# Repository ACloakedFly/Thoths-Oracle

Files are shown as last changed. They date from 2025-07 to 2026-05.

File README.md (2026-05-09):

# Thoth's Oracle
## Table of Contents:
- [Features](#Features)
- [Make your own](#Make-your-own)
- [How it works](#How-it-works)
  - [Hardware](#Hardware)
  - [Software](#Software)
  - [Firmware](#Firmware)
- [Configuration](#Configuration)
- [FAQ](#FAQ)
- [Installation](#Installation)
  - [Windows](#Windows)
    - [Launch on startup](#Windows-launch-on-startup)
  - [Linux](#Linux-Tested-on-Ubuntu)
    - [Example](#Example)
    - [GNOME Specific](#GNOME-Specific)
    - [Linux launch on startup](#Linux-launch-on-startup)
    - [Phone Connection](#Phone-connection-to-linux)
- [License](#License)

### USB operated media display/controller for Windows, Linux(, MacOS WIP).

USB music display helps you keep track of what you are listening to without taking up precious screen space. Thoth's Oracle provides a one stop shop for checking on the current media information and basic controls such as skipping tracks, playing and pausing and adjusting the volume.



# Features:

- Software agnostic companion app listens to operating system rather than a specific program like Spotify app or Firefox
  - If OS is aware of media, companion app will be as well
- 320x480 IPS display for maximum readability
- Display the available metadata of current media
  - Thumbnail
  - Title
  - Album
  - Artist
  - Duration and current position
- Basic media control
  - Play/pause
  - Skip track
  - Previous track
  - Mute/unmute
  - Volume control
- Tiltable screen
- Brightness control
- Lightweight companion app (peak RAM usage <80MB, avg <50MB)
- Wallpaper mode to cycle through local images in Wallpaper folder
- Standard components allowing for custom configuration and ease of assembly
  - Hotswappable MX style or Kailh Choc low-profile style switches
  - 6mm rotary potentiometer and encoder
  - 3D printed shell
  - One screw size
  - Small PCB with mostly THT components. Only the hotswap sockets are SMD (hand solderable)

# Make your own!

Everything you need to make your own should be in BOM-and-Assembly. Let me know if anything can be improved.

# How it works:

## Hardware:

- An ESP32-S3 zero controls all of the device inputs and displays information on screen
- ESP32 communicates with PC over USB C OTG connection

## Software:

- The software is written in C# for the Windows App.
- Companion app catches changes to focused media broadcast from the operating system.
- On media change, Thoth requests metadata, packages it, then waits for signal from the Oracle that it is ready to receive the data.
- Metadata is packaged as follows with header tag denoting type, size, etc.:
  - System information containing date and time
  - Media duration and position
  - Media text: title, album, artist
  - Thumbnail
- All text is converted to UTF-8.
- Once ready signal is received, Thoth sends a package over serial port, waits for ready signal, then proceeds to next package.
- When input commands are received, Thoth requests the OS completes the action.

## Firmware:

- The firmware is written in C.
- All serial communications are handled by Core 1. Core 0 handles all display features running LVGL.
- Thoth's Oracle emits ready signal periodically while idling, and emits control commands as soon as they are inputted by the user.
- When data is received, the header tag is analyzed to know which buffer it should be put in.
- If there is an error with the header tag, all subsequent data is dumped, and firmware waits for a pause in data transmission before resetting header information and buffers, and returning to idle state.
- If no errors are detected, data is placed directly into the correct buffer for further analysis in the case of text data, or displayed immediately for images (rolling effect as image loads).
- Media text starts as one big array of characters, and is split into the three fields using escape characters inserted by companion app.
- The font used is DejaVu-Sans in 16 point, with as much of the character set as is hopefully reasonable to ensure maximum language compatibility, without containing the entire set.
- Once the expected number of bytes is received based on the header tag, the header is reset, Oracle emits a ready signal, then enters idle state.
- If firmware times out before receiving expected data, header tag is reset and device enters idle state.

# Configuration:

 The following can be configured from companion app or config file
- Which program to listen to
- Port the device is connected to
- Sensitivity of volume knob
- Which output device to control (default, speakers, headphones, etc.)
- Wallpaper mode

# FAQ:

Someone ask me something, please.

# Installation:

### Windows:

Companion app is provided as portable application that doesn't need installation. Just download and extract the software file for your system wherever you want and run it!

#### Windows launch on startup:
- Right click on .exe and select 'Create shortcut'
- Copy the shortcut to %APPDATA%\Microsoft\Windows\Start Menu\Programs\Startup

### Linux (Tested on Ubuntu):

- Extract folder to desired location.
- Edit .desktop file to match new location if you want app to appear in Apps list.
- Validate and install
```
desktop-file-validate thoths_oracle.desktop
desktop-file-install thoths_oracle.desktop
```
- Check which port Oracle is connected to. It should show up as USB ACM device.
- Verify the device's group permissions are rw and note the group.
- Verify you are part of the group.
- Reboot
#### Example:

```
$ sudo dmesg | grep tty
[    0.139832] printk: legacy console [tty0] enabled
[    6.652489] cdc_acm 1-5.2.2:1.0: ttyACM0: USB ACM device
$ sudo chmod g+rw /dev/ttyACM0
$ ls -ld /dev/ttyACM0
crw-rw---- 1 root dialout 166, 0 Dec  2 18:21 /dev/ttyACM0
$ sudo usermod -a -G dialout dominique
$ sudo reboot
```
#### GNOME Specific:
GNOME may need an extension such as [AppIndicator and KStatusNotifierItem Support](https://extensions.gnome.org/extension/615/appindicator-support/) to display the menu along the top panel. Otherwise, the program will run normally but all settings will have to be changed through the configuration file.

#### Linux launch on startup:
Using Startup Applications Preferences:
-  Add a new entry named Thoths Oracle.
-  If you have installed the .desktop file, set the command to gtk-launch thoths_oracle.desktop
-  Otherwise, change the command to the location you extracted Thoth's Oracle in.
    - eg. /home/dominique/Documents/Programs/Thoths_Oracle_linux/Thoths_Oracle
- Add a comment if desired and save.

#### Phone connection to Linux:
To use audio from phone with all the same features, install [GSConnect](https://github.com/GSConnect/gnome-shell-extension-gsconnect/wiki) for GNOME, or [KDE Connect](https://kdeconnect.kde.org/) for KDE Plasma and follow the instructions to set it up.  
Add kdeconnect or gsconnect to config.yaml in MonitoredProgram section.  
Next, connect phone (source) to Linux (sink) through bluetooth for audio.  
Done!  

# License:

Thoth's Oracle is licensed under GPL-3.0

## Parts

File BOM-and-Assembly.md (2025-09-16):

# BOM

## Hardware
| Qty | Item | Notes |
| ---- | -- | ---|
| 7 or 9 | M3x20 SHCS | [Example](https://www.aliexpress.com/item/32810872544.html?spm=a2g0o.order_list.order_list_main.31.5b9d1802S5DEg1) |
| 2 | M3x16 SHCS | (optional) shorter screws can be used for the thumbscrews. |
| 9 | M3x4x5 (Screw, height, outer diameter) brass heatset inserts | [Example](https://www.aliexpress.com/item/1005003582355741.html?spm=a2g0o.order_list.order_list_main.63.5b9d1802S5DEg1) |
| 2 | 6mm shaft guitar knobs | 18mm outer diameter works well. Knobs are 38mm apart, so anything larger might get tight. [Example](https://www.aliexpress.com/item/1005003800832352.html) |
| 3 | Keycaps for the switches | [Example](https://www.aliexpress.com/item/1005002976015114.html) |

## Electronics
| Qty | Item | Product Number | Notes |
| --- | -- | -- | --- |
| 1 | PCB |  | Can be purchased from PCBWay or JLCPCB or similar using the Thoths_Oracle_PCB_xxx.rar file in the latest release | 
| 1 | 3.5" 320x480 SPI display | [MSP3525](https://www.lcdwiki.com/3.5inch_IPS_SPI_Module_ST7796) | ST7796U will work, ILI9488 should work but has not been tested. [link](https://www.aliexpress.com/item/1005005878590372.html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) to the IPS display I use. |
| 1 | ESP32-S3 zero | [ESP32-S3-Zero](https://www.waveshare.com/wiki/ESP32-S3-Zero) | As long as it has the ESP32-FH4R2 chip it will work. Presoldered headers are nice |
| 3 | Mechanical keyboard switches |  | Standard MX pinout or Kailh Choc V2 will work. [MX](https://www.cherry.de/en-gb/product/mx2a-red), [Choc V2](https://www.kailh.net/products/kailh-choc-v2-low-profile-switch-set)|
| 3-6 | Matching hotswap sockets | [PG1511](http://www.kailh.com/en/Products/Ks/HPC/), [PG1350](https://cdn.shopify.com/s/files/1/0588/1108/9090/files/5118-Choc-Socket.pdf?v=1686715063) | PG1511 for standard, or PG1350 for Choc V2. Both types can be installed on the same switch location if you want to experiment. |
| 1 | EC11 rotary encoder | [EC11E15244G1](https://tech.alpsalpine.com/e/products/detail/EC11E15244G1/) | A 12.5mm long shaft will work. Longer would be better. |
| 1 | RV09 rotary potentiometer | [RV09BCF-40](https://www.taiwanalpha.com/downloads?target=products&id=72) | A 12.5mm long shaft will work. Longer would be better. |
| 2 | female header sockets 1x9 pins | [66951-009LF](https://www.digikey.com/en/products/detail/amphenol-cs-fci/66951-009LF/1002554) | Ideally 8.4mm insulation height. Longer header sockets can be cut shorter (eg. 1x20 cut to two 1x9s) |
| 1 | XH 2.5mm horizontal male header 1x8 pins | [S8B-XH-A-1](https://www.digikey.com/en/products/detail/jst-sales-america-inc/S8B-XH-A-1/9961927) |
| 1 | JST 2.5mm connector cable 1x8 pins | [XHP-8](https://www.digikey.com/en/resources/datasheets/jst/xh-connector) | These can be found as [preassembled cables](https://www.aliexpress.com/item/4000698884218.html?spm=a2g0o.order_list.order_list_main.5.5e661802USnLWp). At least 5cm is needed but it might be hard to route. 10cm works fine. |
| 1 | USB-C data cable | | C to C or C to A depending on your preference |

## 3D Prints
| Qty | Item |
| --- | -- |
| 1 | Oracle_inputs_plate.stl |
| 1 | Oracle_inputs.stl |
| 1 | Oracle_screen_plate.stl |
| 1 | Oracle_screen.stl |
| 2 | Oracle_thumbscrew.stl |
| 2 | Oracle_thumbscrew_cap.stl |

# Shell Instructions

## 3D Printing

All STLs are in the correct orientation for printing. The Oracle_inputs STL is the only one that needs supports. Any stiff material should work fine (I used PLA).
Here are the support settings I have found to work well
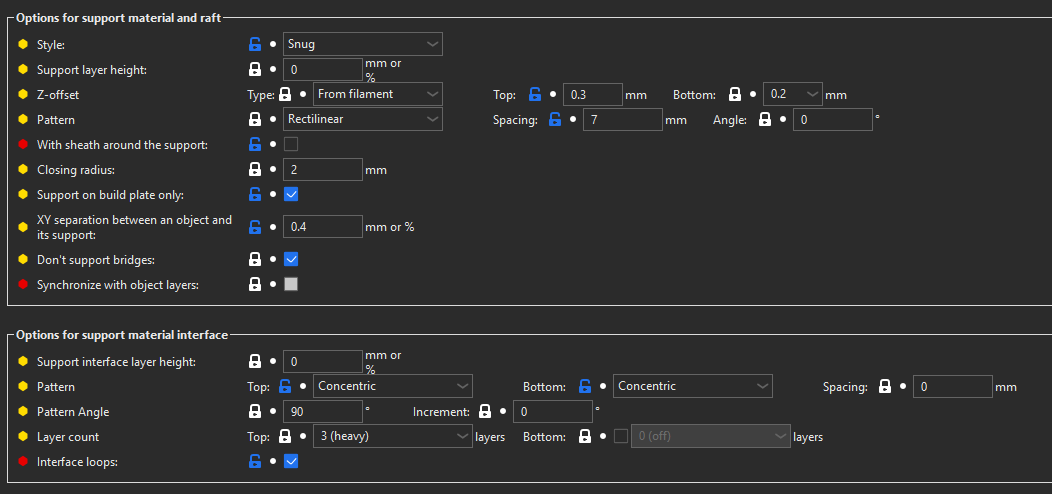
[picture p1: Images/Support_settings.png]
Support_settings


# PCB Assembly and Heat Sets Instructions

**Disclaimer:** I am not the best solderer. This is more for where everything goes, and an order that works. You do not need to be a highly skilled solderer to do this. 
If you are new at this, I recommend watching tutorials and safely practicing a bit. 

**Required Tools and Materials**
- Solder
- Soldering iron
- Ventilation fan
- Safety glasses
- M2.5 hex bit
- M2.0 hex bit
- Flush cutters
- Pliers

Collect the components. Only one set of hot swap sockets is required, both can be used.

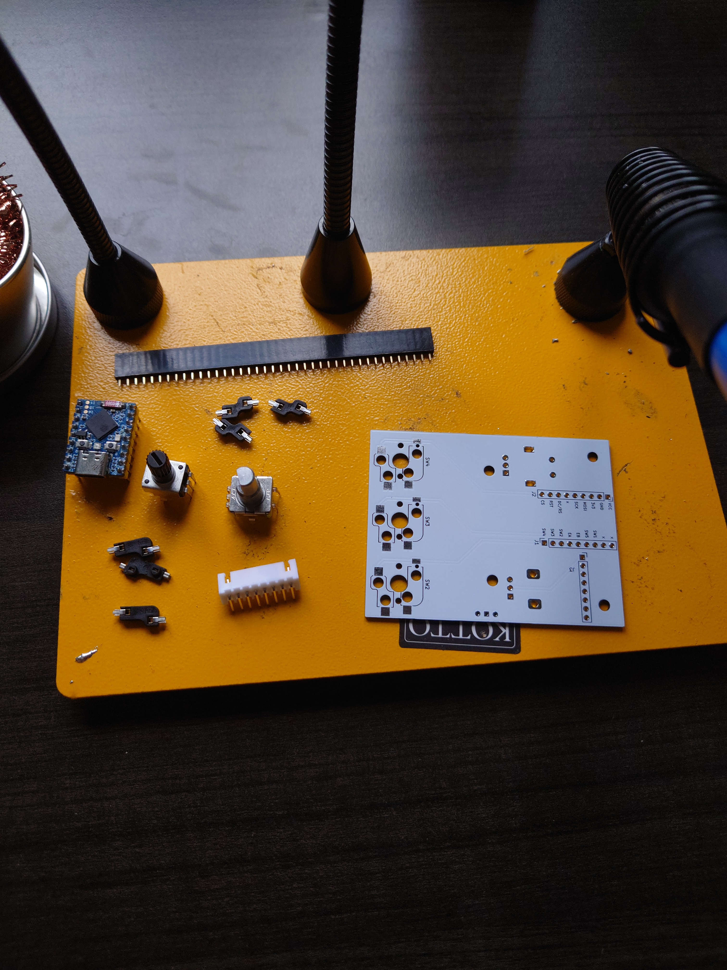
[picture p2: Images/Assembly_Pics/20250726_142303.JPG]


If you are using header sockets longer than 9 pins, snip across the 10th.

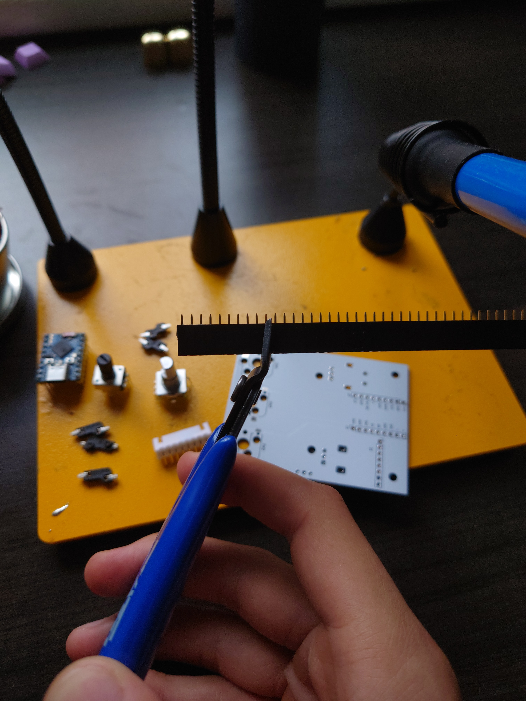
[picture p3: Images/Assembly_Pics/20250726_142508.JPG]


The cut end will need to be cleaned up. This can be done with the snips.

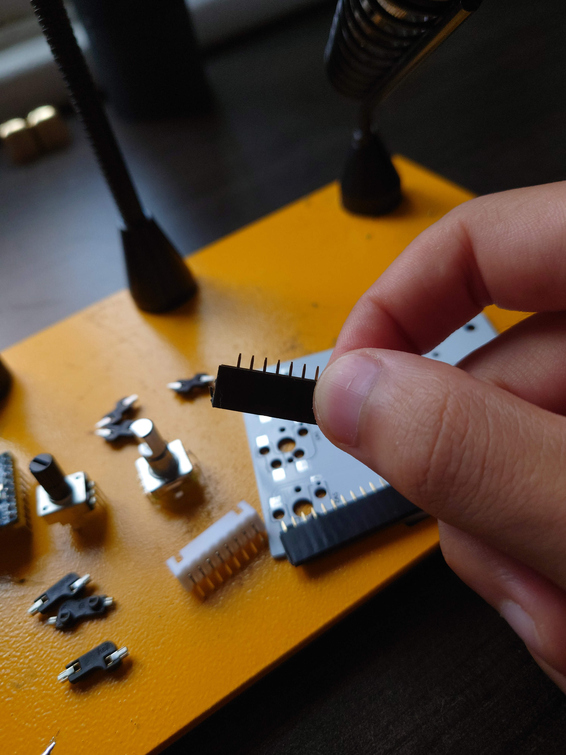
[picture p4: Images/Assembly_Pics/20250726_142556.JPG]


Try not to cut too far into the next socket. Repeat for the second row.

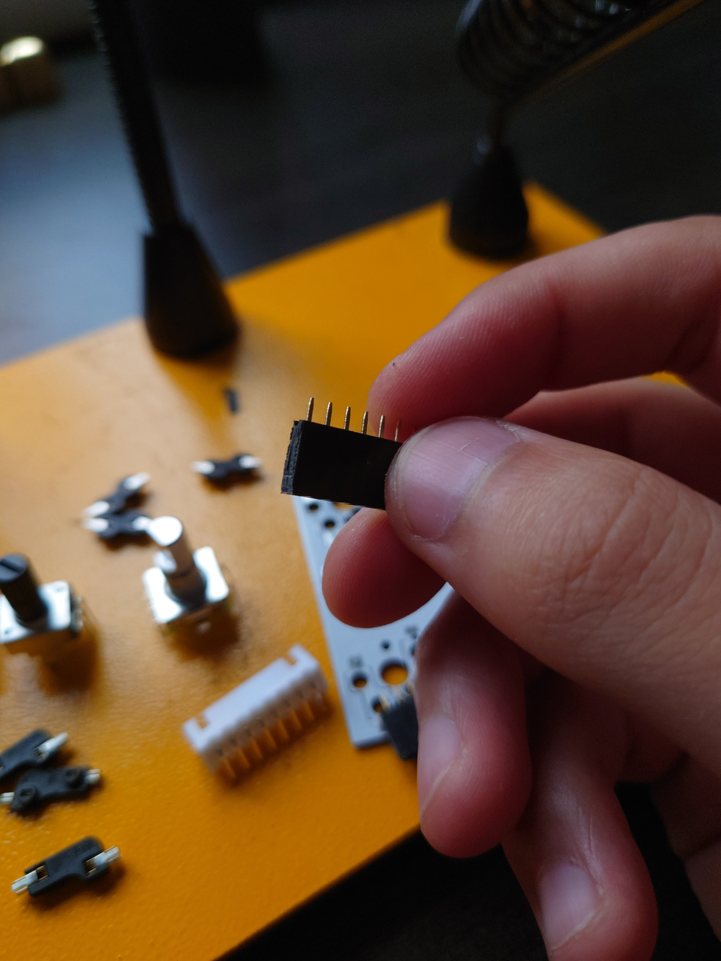
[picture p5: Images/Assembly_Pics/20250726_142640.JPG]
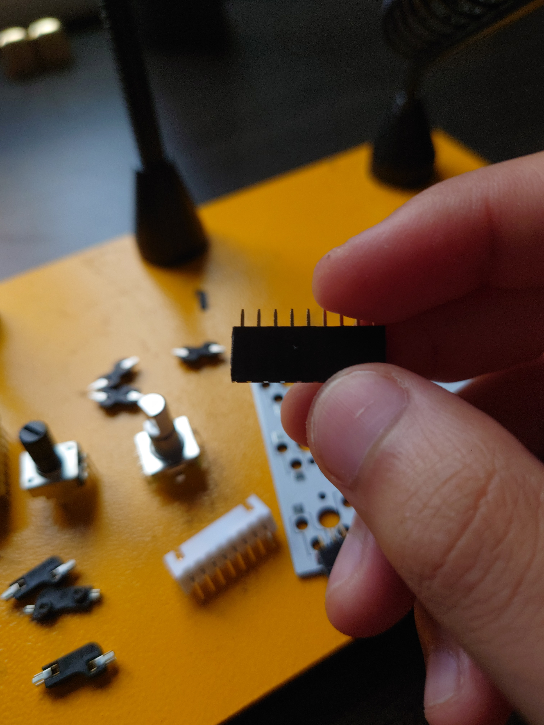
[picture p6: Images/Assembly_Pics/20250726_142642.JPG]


Depending on which hot swap sockets you are using, place them in the corresponding holes and solder them onto the pads.

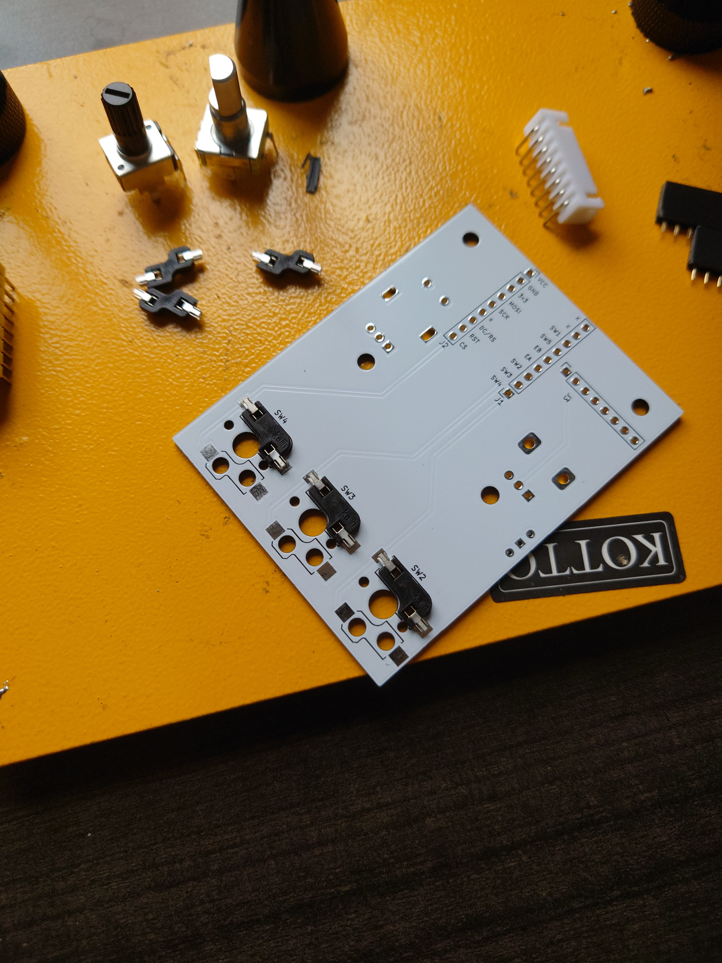
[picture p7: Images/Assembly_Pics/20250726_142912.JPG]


Yikes! But it will do. These are only switches, so precision is not required.

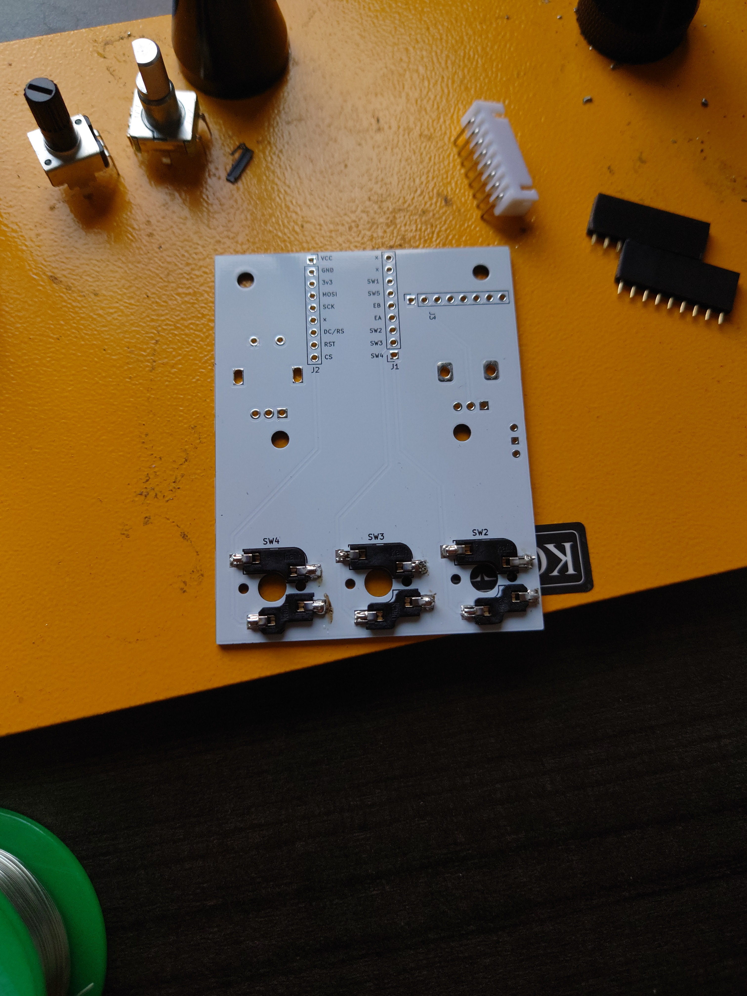
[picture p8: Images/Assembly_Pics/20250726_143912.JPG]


The pins for the screen go on the same side as the hotswap sockets. So solder them from the top of the board.



For the ESP32, placing the sockets on its header pins keeps them straight.



They also go on the bottom of the board, same as the screen pins. If you are worried about overheating the ESP32, solder a couple pins on each row to keep them steady, then remove the ESP32.



The rotary encoder and potentiometer go on the top of the board.



Hopefully your board looks better than mine!



Soldering is complete!
The iron will still be needed for the heat set inserts.

All the heat set inserts should be pressed flush with their top surfaces. A few of them are fairly close to tall walls, so I found it easier to press them in with the side of the soldering tip once they were hot enough to go in with not much force.





That's the end of the soldering iron.

# Final Assembly Instructions

The PCB goes into the shell with the ESP facing outwards.



As you slide the PCB into the shell, pull the wall with USB hole away from the ESP32 slightly to clear the USB port. The port should fit snuggly into the hole afterwards.



Screw the inputs plate onto the shell



Line up the screen with the heat sets and connect the ribbon cable. Make sure GND through LED are the ones connected.



Screw the screen plate on.



Line up the plug with the hole in the inputs shell, then push it in until it is fully seated.



The two halves can now be put together. It will be a tight fit.



Place the screw as far into the thumbscrew without pushing the head into it. The cap needs to be aligned with the screw first.



Push the cap into the head and line the tabs up with the hole.



Flip the whole thing over and push the thumbscrew down until everything is pressed into place. Repeat these steps for the second thumbscrew.



Screw each thumbscrew into the screen.



Depending on the length of your potentiometer and encoder shafts, the knobs might drag along the shell. So lift them up a little before securing them with the grub screw. This is especially important for the encoder to keep the switch functioning.



Try to make sure the pins on your switches are fairly straight. The pin on the left might be too crooked to fit nicely. 



Line up the pins and push the switches into place. The keycaps go on next.



Your build is complete!



# Firmware Flashing Instructions

- Connect your ESP32 to your computer with a USB cable, then find out which port it is connected to either using Thoth's Oracle Software or through your OS.
- Download the ESP flashing tool from [here](https://docs.espressif.com/projects/esp-test-tools/en/latest/esp32s3/production_stage/tools/flash_download_tool.html), then extract the folder.
- Download and extract the latest release of Thoths_Oracle_Firmware. Place all three files into the bin folder of the flashing tool.
- Run the flashing tool exe.
- Set the chip type to ESP32-S3, Workflow to Develop, and Load mode to UART, then click OK.
- Set up the next screen according to the screenshot below, ensuring the COM matches the port your ESP32 is connected to.
- Press start and let the tool finish.
- The tool does not restart the ESP32, so if you are doing this when the Oracle is assembled, disconnect and reconnect the USB cable and it should start displaying. 
  
flashing_instructions

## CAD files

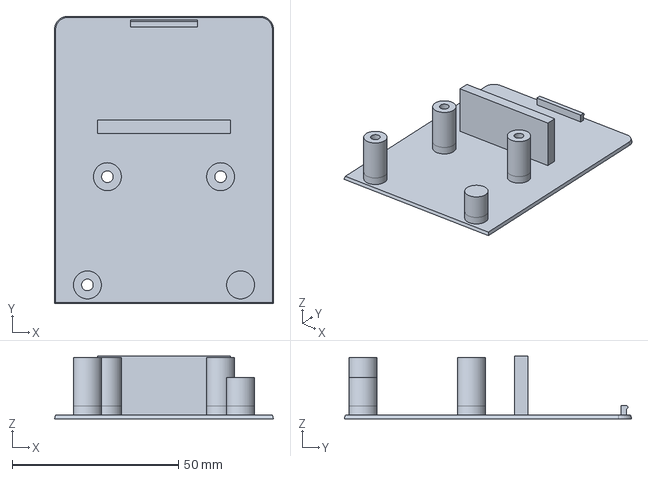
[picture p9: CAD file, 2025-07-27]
Shell/CAD/Oracle_inputs_plate.FCStd
65.8 x 86.3 x 18.8 mm

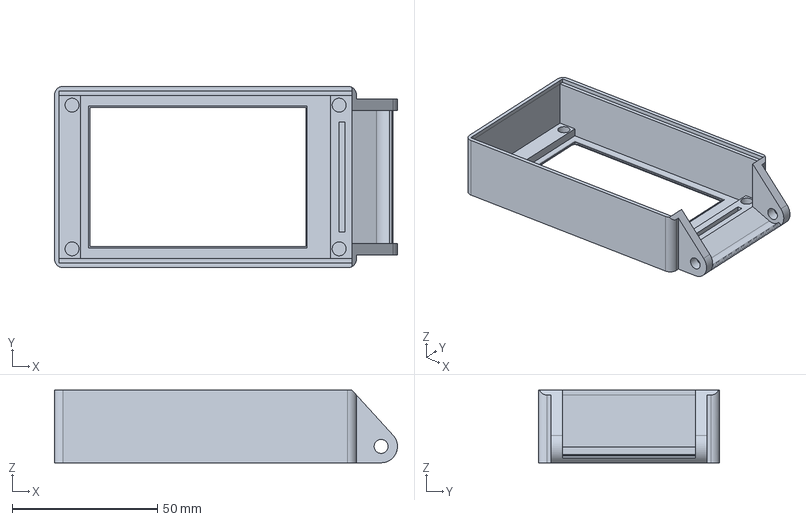
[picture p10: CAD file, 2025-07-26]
Shell/CAD/Oracle_screen.FCStd
118.1 x 62.5 x 25.0 mm

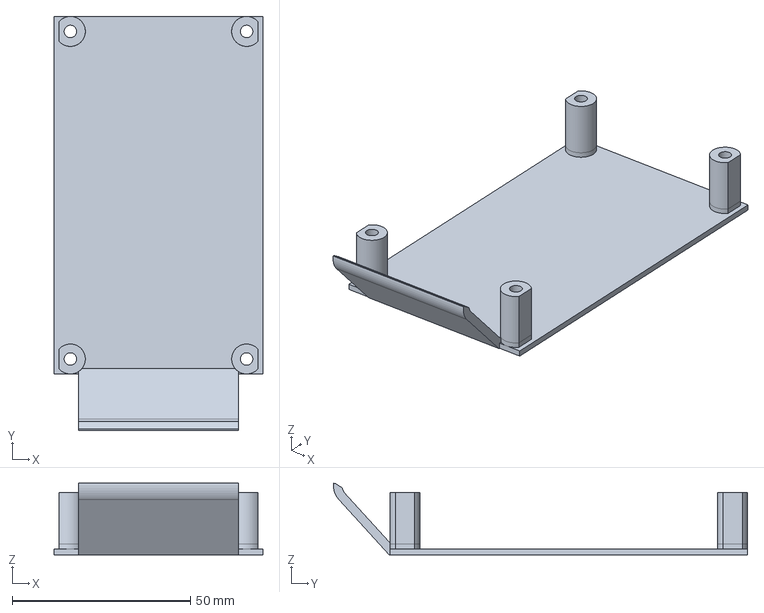
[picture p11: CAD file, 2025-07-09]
Shell/CAD/Oracle_screen_plate.FCStd
58.7 x 116.3 x 20.1 mm

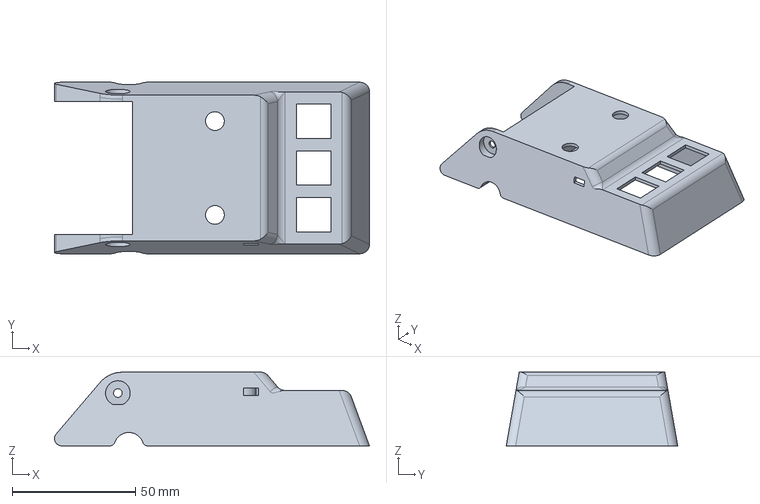
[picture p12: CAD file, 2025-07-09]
Shell/CAD/Oracle_inputs.FCStd
127.7 x 69.5 x 29.9 mm

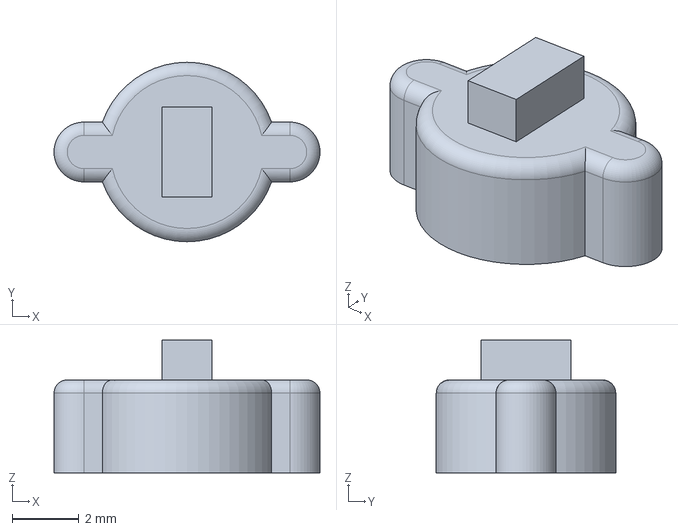
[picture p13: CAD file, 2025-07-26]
Shell/CAD/Oracle_thumbscrew_cap.FCStd
8.00 x 5.40 x 4.00 mm

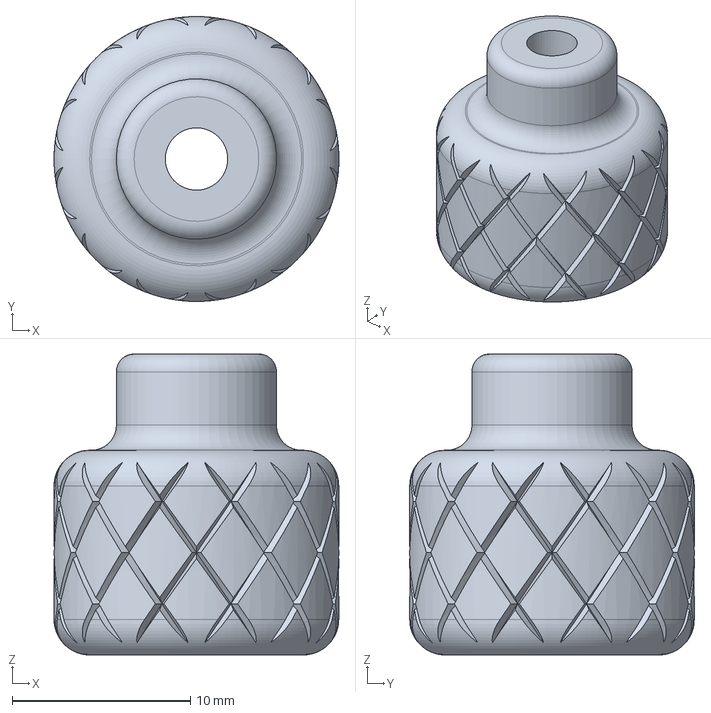
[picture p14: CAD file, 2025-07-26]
Shell/CAD/Oracle_thumbscrew.FCStd
16.0 x 16.0 x 16.9 mm

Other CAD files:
Shell/STLs/Oracle_inputs.stl
Shell/STLs/Oracle_inputs_plate.stl
Shell/STLs/Oracle_screen.stl
Shell/STLs/Oracle_screen_plate.stl
Shell/STLs/Oracle_thumbscrew.stl
Shell/STLs/Oracle_thumbscrew_cap.stl

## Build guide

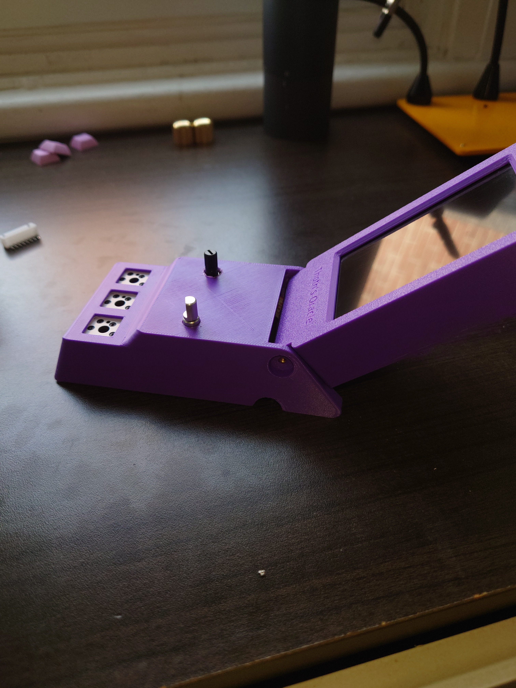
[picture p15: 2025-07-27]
Images/Assembly_Pics/20250726_150715.JPG

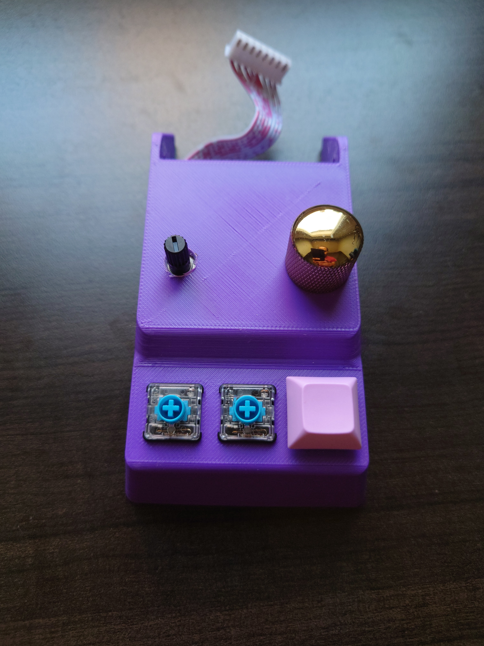
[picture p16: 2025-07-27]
Images/Assembly_Pics/20250724_144334.JPG

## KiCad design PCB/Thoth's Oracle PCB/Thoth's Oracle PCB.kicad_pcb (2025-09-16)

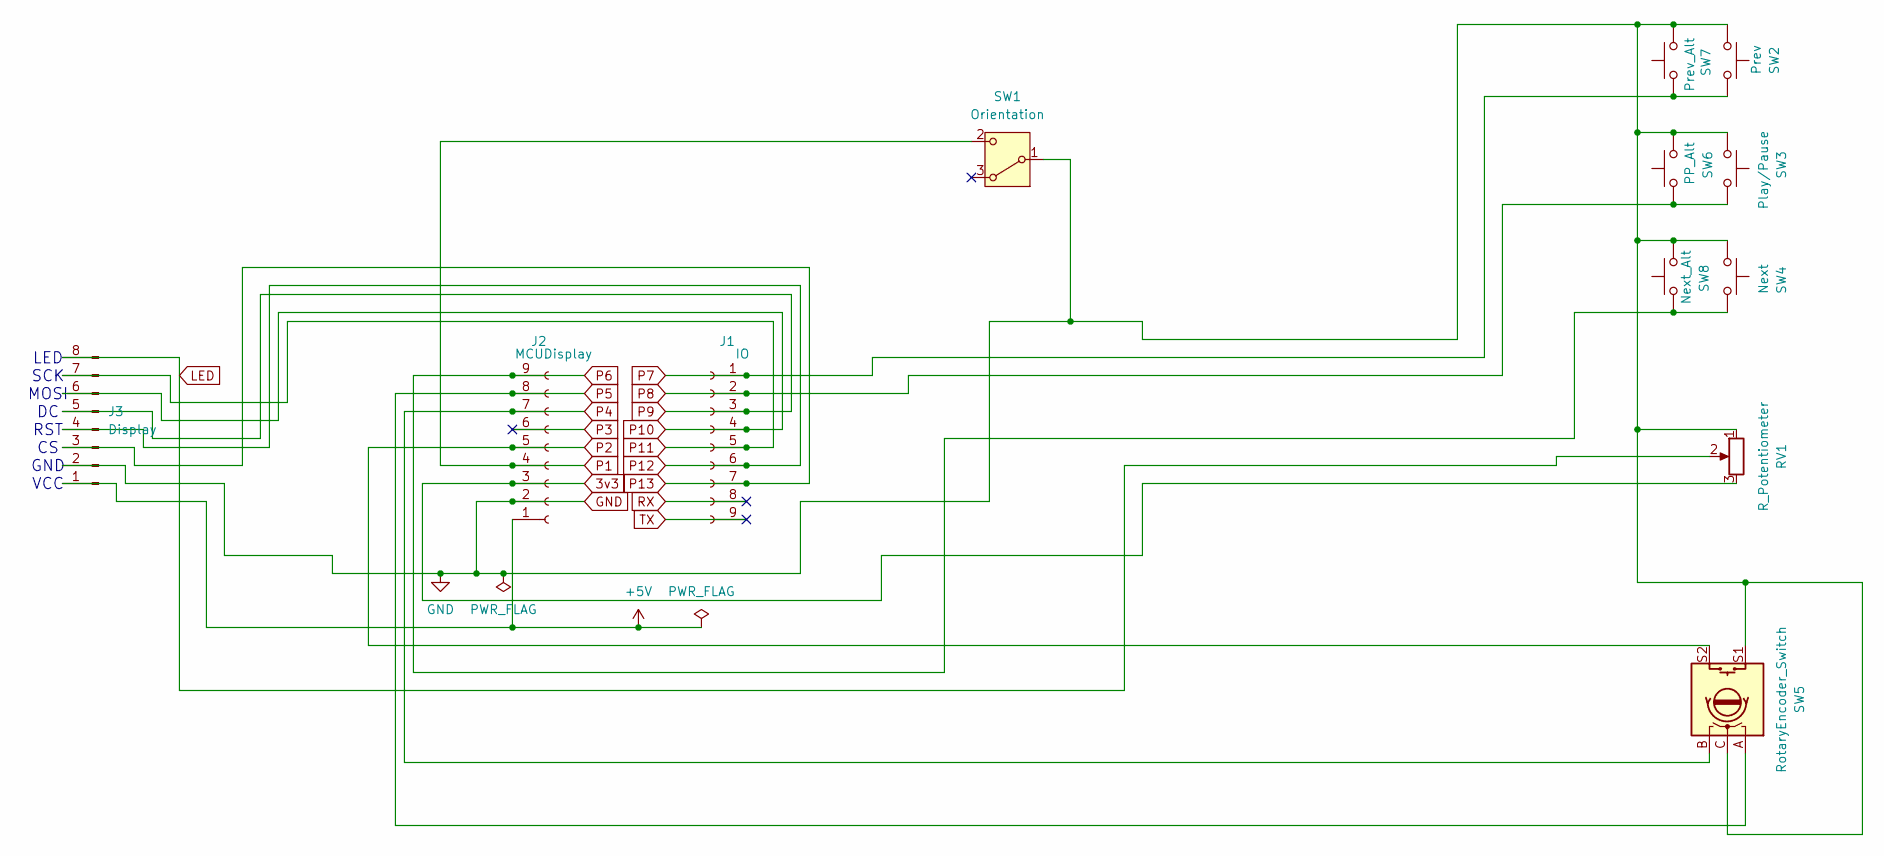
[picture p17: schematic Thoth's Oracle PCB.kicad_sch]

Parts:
J1: IO; PinSocket_1x09_P2.54mm_Vertical
J2: MCUDisplay; PinSocket_1x09_P2.54mm_Vertical
J3: Display; PinSocket_1x08_P2.54mm_Horizontal
RV1: R_Potentiometer; Potentiometer_Alps_RK09K_Single_Vertical
SW1: Orientation; SW_Slide-03_Wuerth-WS-SLTV_10x2.5x6.4_P2.54mm
SW2: Prev; Kailh_socket_MX_modified
SW3: Play/Pause; Kailh_socket_MX_modified
SW4: Next; Kailh_socket_MX_modified
SW5: RotaryEncoder_Switch; RotaryEncoder_Alps_EC11E-Switch_Vertical_H20mm
SW6: PP_Alt; Kailh_socket_PG1350_modified
SW7: Prev_Alt; Kailh_socket_PG1350_modified
SW8: Next_Alt; Kailh_socket_PG1350_modified

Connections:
3v3: J2.3, RV1.3
+5V: J2.1, J3.1
GND: J2.2, J3.2, RV1.1, SW1.1 (B), SW2.2, SW3.2, SW4.2, SW5.C, SW5.S1, SW6.2, SW7.2, SW8.2
LED: J3.8, RV1.2
P1: J2.4, SW1.2 (C)
P2: J2.5, SW5.S2
P3: J2.6
P4: J2.7, SW5.B
P5: J2.8, SW5.A
P6: J2.9, SW4.1, SW8.1
P7: J1.1, SW2.1, SW7.1
P8: J1.2, SW3.1, SW6.1
P9: J1.3, J3.5
P10: J1.4, J3.6
P11: J1.5, J3.7
P12: J1.6, J3.4
P13: J1.7, J3.3
RX: J1.8
TX: J1.9

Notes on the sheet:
LED SCK MOSI DC RST CS GND VCC

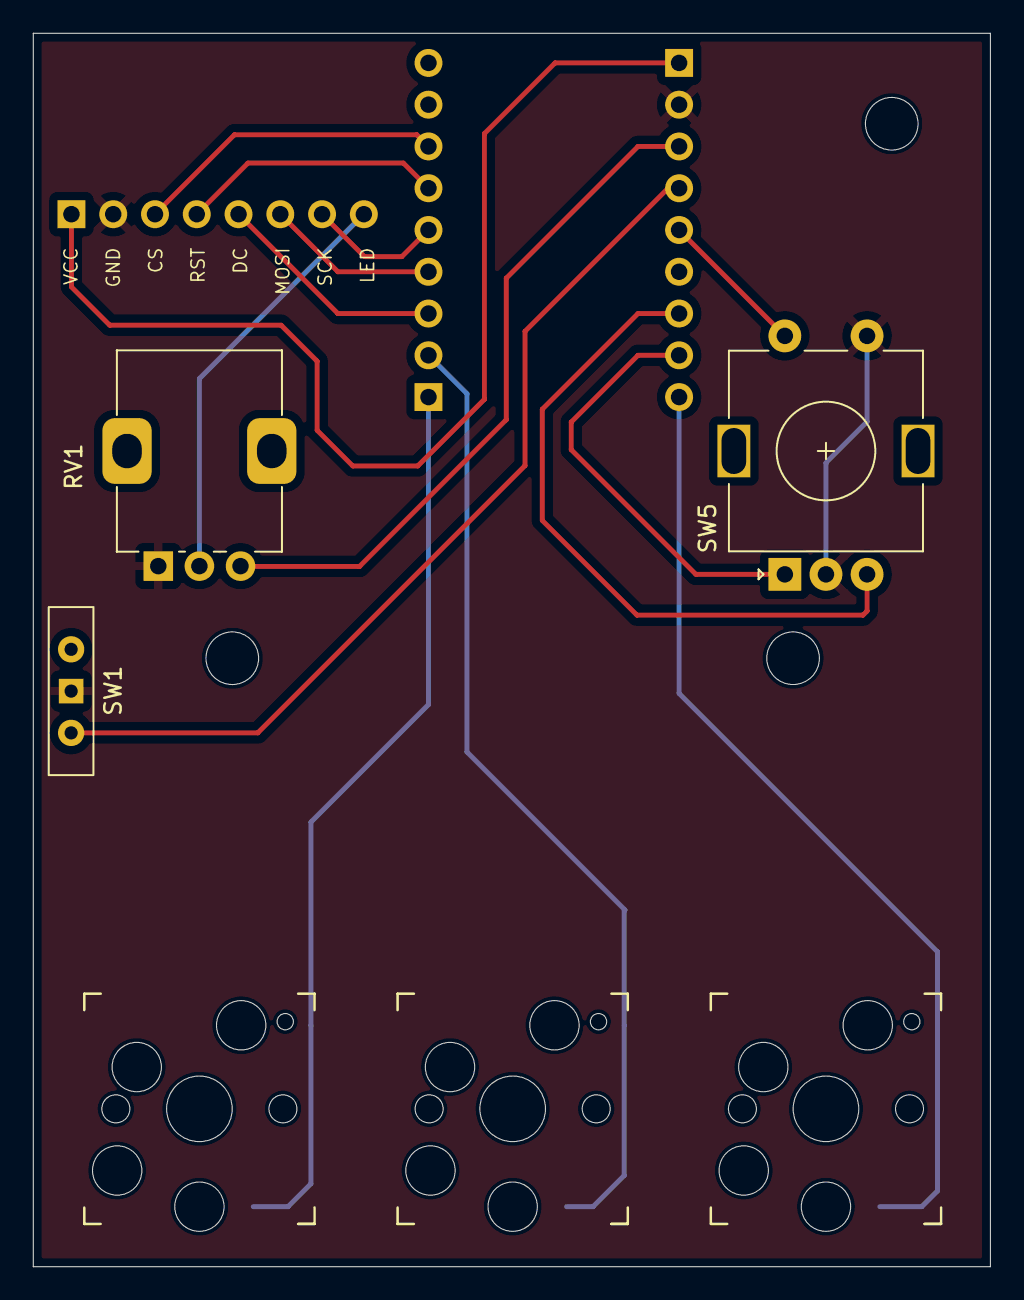
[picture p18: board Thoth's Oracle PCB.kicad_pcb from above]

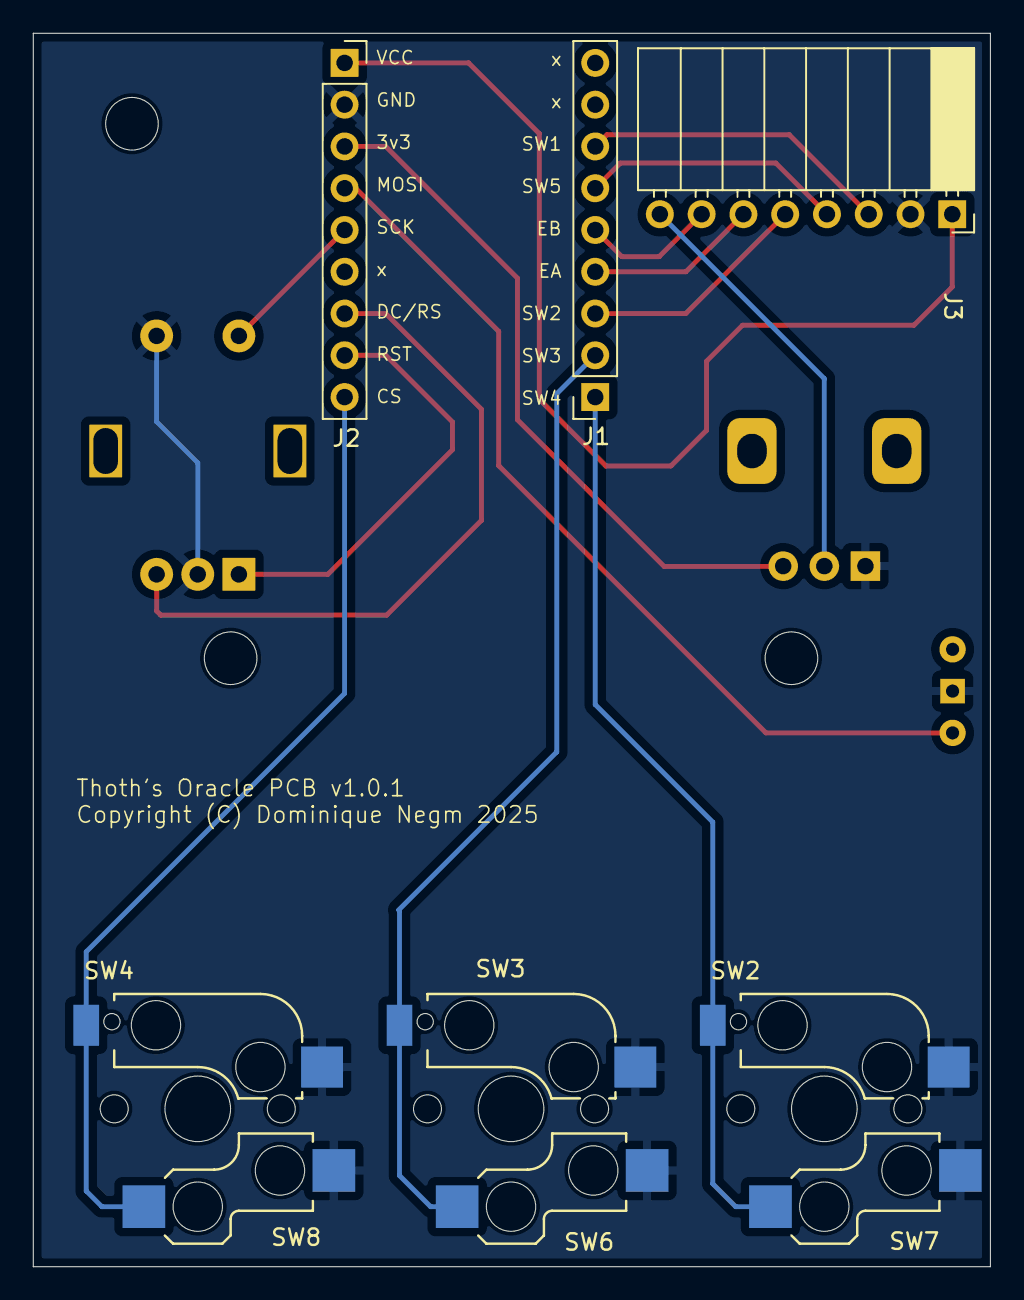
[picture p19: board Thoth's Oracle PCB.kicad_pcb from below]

Board: 2 copper layers, 58.2 x 75.0 mm, 12 parts (3 on the bottom side), 16 nets.

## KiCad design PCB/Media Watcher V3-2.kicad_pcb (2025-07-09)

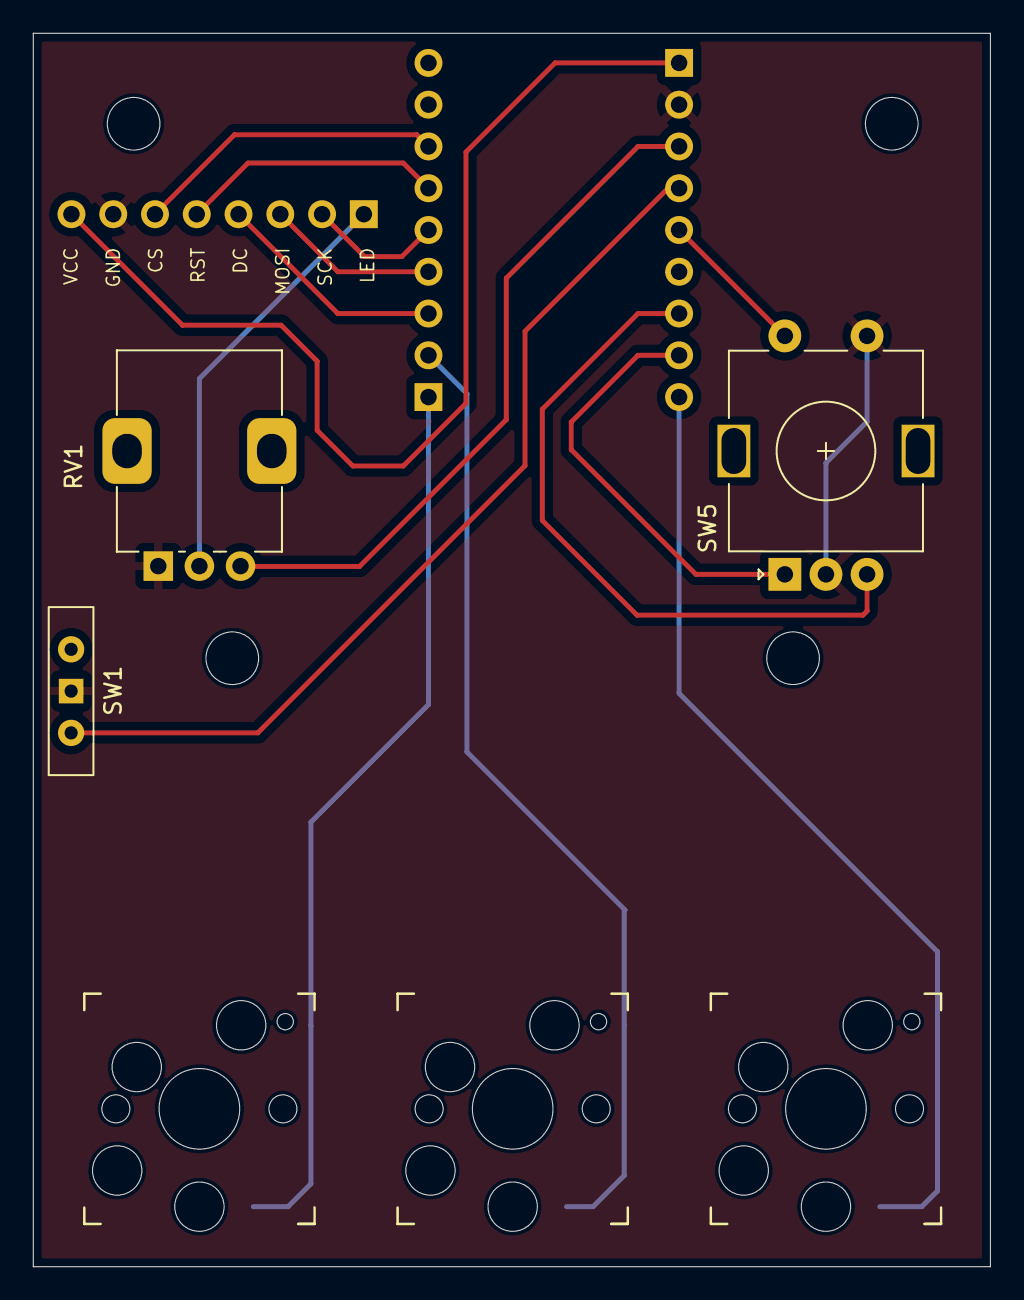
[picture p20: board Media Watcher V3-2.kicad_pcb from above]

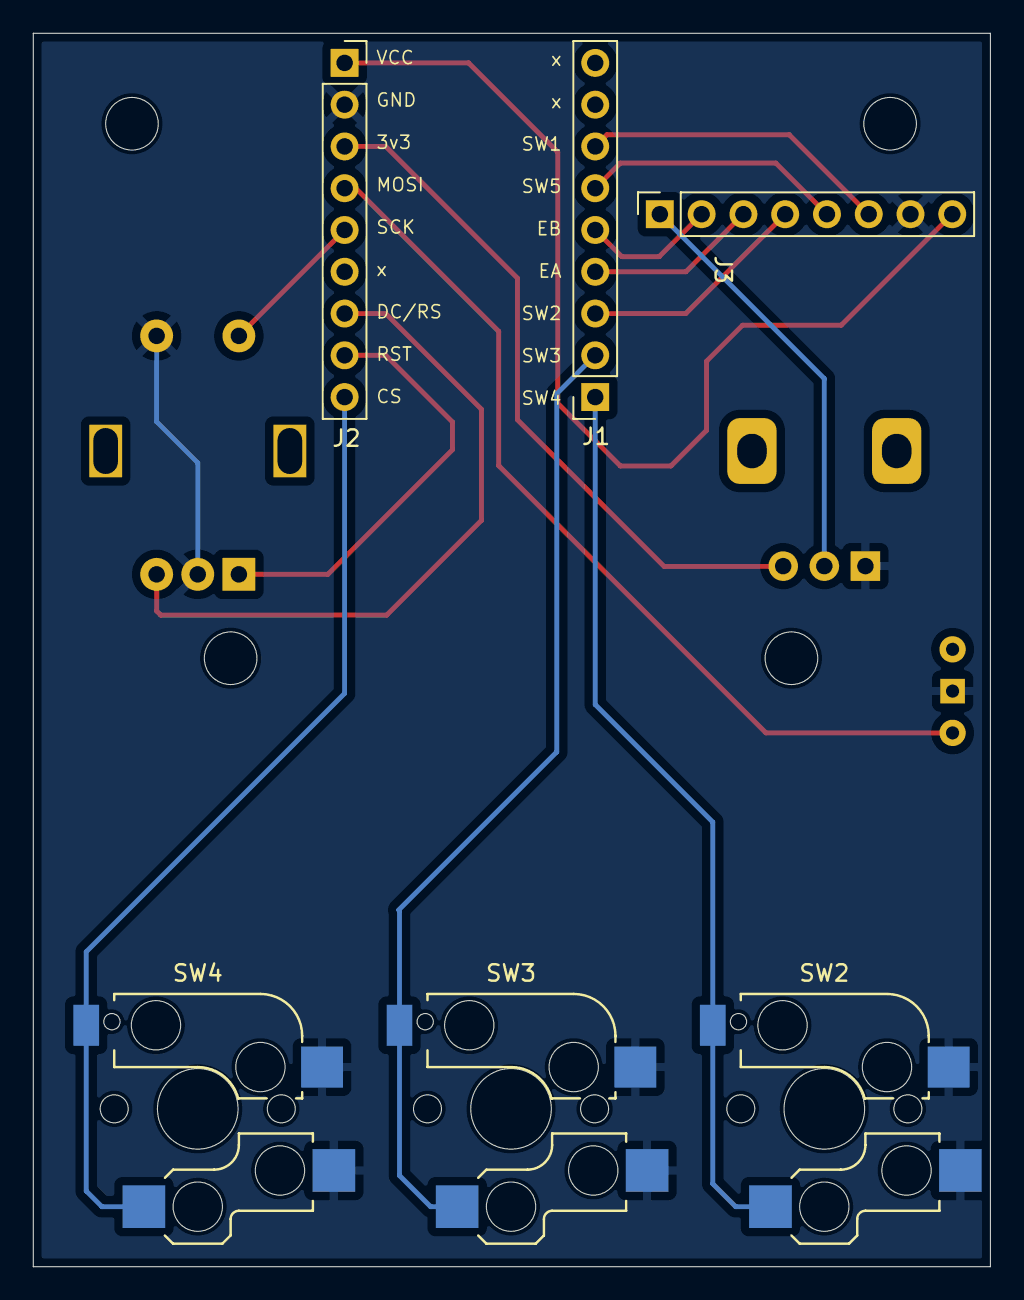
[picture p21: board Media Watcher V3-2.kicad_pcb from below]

Board: 2 copper layers, 58.2 x 75.0 mm, 9 parts (3 on the bottom side), 16 nets.

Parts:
J1: IO; PinSocket_1x09_P2.54mm_Vertical
J2: MCUDisplay; PinSocket_1x09_P2.54mm_Vertical
J3: Display; PinSocket_1x08_P2.54mm_Vertical
RV1: R_Potentiometer; Potentiometer_Alps_RK09K_Single_Vertical
SW1: Orientation; SW_Slide-03_Wuerth-WS-SLTV_10x2.5x6.4_P2.54mm
SW2: Prev; Kailh_socket_MX_PG1350
SW3: Play/Pause; Kailh_socket_MX_PG1350
SW4: Next; Kailh_socket_MX_PG1350
SW5: RotaryEncoder_Switch; RotaryEncoder_Alps_EC11E-Switch_Vertical_H20mm

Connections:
3v3: J2.3, RV1.3
+5V: J2.1, J3.8
GND: J2.2, J3.7, RV1.1, SW1.1 (B), SW2.2, SW3.2, SW4.2, SW5.C, SW5.S1
LED: J3.1, RV1.2
P1: J2.4, SW1.2 (C)
P2: J2.5, SW5.S2
P4: J2.7, SW5.B
P5: J2.8, SW5.A
P6: J2.9, SW4.1
P7: J1.1, SW2.1
P8: J1.2, SW3.1
P9: J1.3, J3.4
P10: J1.4, J3.3
P11: J1.5, J3.2
P12: J1.6, J3.5
P13: J1.7, J3.6

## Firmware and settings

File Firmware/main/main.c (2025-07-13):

/*
===========================================================================
Copyright (C) 2025 Dominique Negm

This file is part of Thoth's Oracle source code.

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
You should have received a copy of the GNU General Public License
along with Thoth's Oracle; if not, see <https://www.gnu.org/licenses/>
===========================================================================
*/
// main.c

#include "data.h"

TaskHandle_t LCDTask, uart_task, uart_writer_task, update_info, ticker_task;
const char TAG[] = {"dev"};

//We just set up the mutexes and the tasks
void app_main(void){
    esp_log_level_set(TAG, ESP_LOG_INFO);
    info_mutex = xSemaphoreCreateBinary();
    xSemaphoreGive(info_mutex);
    img_mutex = xSemaphoreCreateBinary();
    xSemaphoreGive(img_mutex);
    date_time_mutex = xSemaphoreCreateBinary();
    xSemaphoreGive(date_time_mutex);
    ui_setup(NULL);

    //Keep the ui and serial communications segregated to their own cores to minimize any waiting on each other. 
    //Also LVGL is not thread safe (aside from lv_tick_inc which should be at higher priority)
    xTaskCreatePinnedToCore(timer_incer,"ticker_task", configMINIMAL_STACK_SIZE*2,NULL,1,&ticker_task,0);//should be higher priority than ui_task
    xTaskCreatePinnedToCore(UpdateInfo,"ui_task", configMINIMAL_STACK_SIZE*2,NULL,10,&update_info,0);

    xTaskCreatePinnedToCore(serial_task, "serial_event_task", 4096, NULL, 5, &uart_task, 1);
    xTaskCreatePinnedToCore(inputs_main, "inputs_task", configMINIMAL_STACK_SIZE + 1000 + 1024, NULL, 1, &uart_writer_task, 1);
}

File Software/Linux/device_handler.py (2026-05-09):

"""/*
===========================================================================
Copyright (C) 2025 Dominique Negm

This file is part of Thoth's Oracle source code.

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
You should have received a copy of the GNU General Public License
along with Thoth's Oracle; if not, see <https://www.gnu.org/licenses/>
===========================================================================
*/
// device_handler.py """
import threading
import serial
from dbus.mainloop.glib import DBusGMainLoop
import dbus
from mpris2 import get_players_uri
from mpris2 import Player
import queue
import time
import datetime
from wand.image import Image
from wand.color import Color as wand_color
from wand import exceptions as wand_exceptions
from config_handler import config_watcher, load_config, logging, URI_FILE, WALLPAPER_FOLDER
import config_handler
import re
import os
from colour import Color

MAX_QUEUE_WAIT = 5 #seconds
WRITER = 0
META = 1
SETUP = 2
global player
global oracle_ready
oracle_ready = True
global oracle_serial
oracle_serial = None
global oracle_config
global old_config
global read_thread
global serial_reading
serial_reading = False
global serial_writing
serial_writing = True
global meta_reading
meta_reading = True
global setting_up
setting_up = True
global duration
duration = 0
global images
images = []
global wallpaper_index
wallpaper_index = 0
global wallpaper_num
global wallpaper_mode
global wallpaper_period
global wallpaper_timer
global wallpaper_paused
wallpaper_paused = False
wallpaper_period = 0
wallpaper_mode = False
wallpaper_num = 0
global meta_thread
global meta_queue
global queued_media
queued_media = False
global writer_queue
global writer_thread
global setup_thread
global exitting
global status_signal
global seeked_signal
global bus
global media_check_thread
global media_handler
global player_uri
player_uri = ""
global reconnect
reconnect = True

MAX_ATTEMPTS = 20
#Message types
IMG_TAG =       1
TEXT_TAG =      2
SYS_MSG_TAG =   3
DUR_POS_TAG =   4
CMD_TAG =       5
INFO_TAG =      6
STATUS_TAG =    7
FINISHED_TAG =  8
ERROR_TAG =     9
COLOUR_TAG =    10
CODES = ["img_tag", "text_tag", "sys_msg_tag", "dur_pos_tag", "cmd_tag", "info_tag", "status_tag", "finished_tag", "error_tag", "colour_tag"]

def serial_decode(code, cmd):
    global wallpaper_paused
    global queued_media
    if code == ERROR_TAG:
        queued_media = True
    elif code == STATUS_TAG or code == FINISHED_TAG:
        global oracle_ready
        oracle_ready = True
    elif code == CMD_TAG:
        vol_sens = 3 if oracle_config['VolumeSensitivity'] is None else oracle_config['VolumeSensitivity']
        try:
            if cmd == 1:
                player.Volume -= vol_sens/100
            elif cmd == 2:
                player.Volume += vol_sens/100
            elif cmd == 3:
                player.Volume = 0.0
            elif cmd == 4:
                if wallpaper_mode:
                    wallpaper_timer.cancel()
                    next_wallpaper(-1)
                else:
                    player.Previous()
            elif cmd == 5:
                if wallpaper_mode:
                    if wallpaper_paused is False:
                        wallpaper_paused = True
                        pause_wallpaper()
                        wallpaper_timer.cancel()
                    else:
                        wallpaper_paused = False
                        next_wallpaper(0)
                else:
                    player.PlayPause()
            elif cmd == 6:
                if wallpaper_mode:
                    wallpaper_timer.cancel()
                    next_wallpaper()
                else:
                    player.Next()
        except Exception as e:
            logging("serial_decode: " + str(e))

def queue_putter(args, mode = WRITER):
    try:
        match mode:
            case 0:
                writer_queue.put(args, timeout=MAX_QUEUE_WAIT)
                pass
            case 1:
                meta_queue.put(args, timeout=MAX_QUEUE_WAIT)
                pass
            case 2:
                config_handler.setup_queue.put(args, timeout=MAX_QUEUE_WAIT)
                pass
    except queue.Full:
        pass
    except Exception as e:
        logging("queue_putter: " + str(mode) + " | " + str(e))

def serial_reader():
    message = ""
    code = -1
    command = -1
    while serial_reading:
        next_byte = b"\x00"
        try:
            next_byte = oracle_serial.read()
        except Exception as e:
            logging("serial_reader: " + str(e))
            queue_putter("serial_reader", mode=SETUP)
            return -1
        next_int = int.from_bytes(next_byte)
        if next_int == 0:
            continue
        elif next_int < 10:
            if code <= 0:
                code = next_int
            else:
                command = next_int
        elif next_int != 10:
            message += next_byte.decode("utf-8")
        else:
            if code == -1:
                continue
            logging(f"{code} | {command} : {message}")
            serial_decode(code, command)
            message = ""
            code = -1
            command = -1
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

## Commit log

2025-07-09 Added PCB and 3d models
    [MB Inputs Plate v0-1.FCStd, MB Inputs Plate v0-1.stl, MB Inputs v0-9.FCStd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]
2025-07-09 Create PCB Assembly Instructions.md
2025-07-09 Rename PCB Assembly Instructions.md to README.md
2025-07-16 Added Timers for DeviceHandler loop
2025-07-20 Preparing for release
    [Thoth's Oracle PCB.kicad_pcb, Thoth's Oracle PCB.kicad_sch, bom.csv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]
2025-07-23 Added priority to MonitoredProgram and moved it to sessionschanged rather than currentsessionchanged. Updated config to reflect this. Added copyright and version number to exe. If program is firefox,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
2025-07-24 Cleaned board
    [Thoth's Oracle PCB.kicad_pcb, Thoth's Oracle PCB.kicad_sch]
2025-07-24 Cleaned shell
    [MB Screen v0-3.FCStd, MB Screen v0-3.stl, Oracle_inputs.FCStd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]
2025-07-24 Cleaned stl
    [Oracle_thumbscrew.FCStd, Oracle_thumbscrew.stl]
2025-07-24 Fixed thumbscrew orientation
    [Oracle_thumbscrew.FCStd, Oracle_thumbscrew.stl]
2025-07-25 Added queue for media writing thread to let other threads send messages. Fixed a problem with the default config causing errors on first startup
2025-07-27 Added build pictures and updated inputs plate
    [Oracle_inputs_plate.FCStd, Oracle_inputs_plate.stl]
2025-07-27 Added a couple more Assembly_Pics
2025-08-08 Separated hotswap sockets with modified footprints so they don't overlap. Typo in assembly
    [Thoth's Oracle PCB.kicad_pcb, Thoth's Oracle PCB.kicad_sch]
2026-01-13 Fixed the last fix for handling sleep. Last attempt incorrectly used the serial exception handler. New fix uses the mediacheck function to repoll the current media session. Also fixed bug with the co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
2026-01-21 Added more context to input logging, added automatically checking for icons in parent folder rather than changing between testing and "production", Removide subdirectory checking in ConfigHandler, th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
2026-01-22 Added spam protection on config changes App now warns if selected device is not found Fixed small issue with Default Device seemingly being selected if selected device is not found (until something i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
2026-01-22 Now checks if currently selected playback device is default when config set to Default Device. If not default, get new default.
2026-02-09 Added exception hanlder to inputs from device Tweaked default config to have common apps watched by default
2026-02-16 Big changes to linux. Increased stability, added automatic session handling, fixed occasional playback status not being updated
    [device_handler.py]
2026-02-16 Added shortcut to folder for ease of use Added x11 as backend in .desktop file because it seems to not work otherwise Refactored session watching. It could probably use more work to simplify it, but 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
    [device_handler.py, ui_handler.py]
2026-02-18 Added live colour changing to Firmware Added very basic colour changing in Linux software. Right now it is just through the config file, but the plan is a colour picker in the tray icon. This doesn't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
    [data.h, default_config.py, device_handler.py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]
2026-02-22 Fixed sleep causing infinite loop of writing to disk (very not cool) Added file size check to log to not exceed MAX_LOG_SIZE (set to 200 mb for now, probably way too big for production, but good for 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
    [config_handler.py, device_handler.py]
2026-02-26 More stability improvements, reworked uri handling
    [device_handler.py, ui_handler.py]
2026-03-16 Wait do I even need to join every thread?

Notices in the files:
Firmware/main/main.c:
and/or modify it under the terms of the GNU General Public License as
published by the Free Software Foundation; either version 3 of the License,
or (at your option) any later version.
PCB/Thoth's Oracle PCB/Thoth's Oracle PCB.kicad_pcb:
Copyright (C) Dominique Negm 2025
